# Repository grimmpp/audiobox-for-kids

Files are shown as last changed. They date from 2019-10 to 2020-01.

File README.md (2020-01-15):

# AudioBox for Kids (Arduino and DFMiniPlayer Project)
This project is about an audiobox which allows small kids, who cannot read, don't understand signs, or don't know which button to push, an easy way to choose sound effects, audio books, or music tracks. Playing tracks can be done by putting small items on the top of the audiobox. Those items are related to the e.g. audio book kids want to play and can be e.g. small figures or labelled cards or other NFC tags. 
<br />
<table border=0><tr>
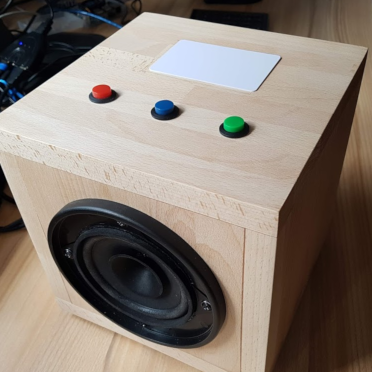
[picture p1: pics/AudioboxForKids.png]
  <td></td>
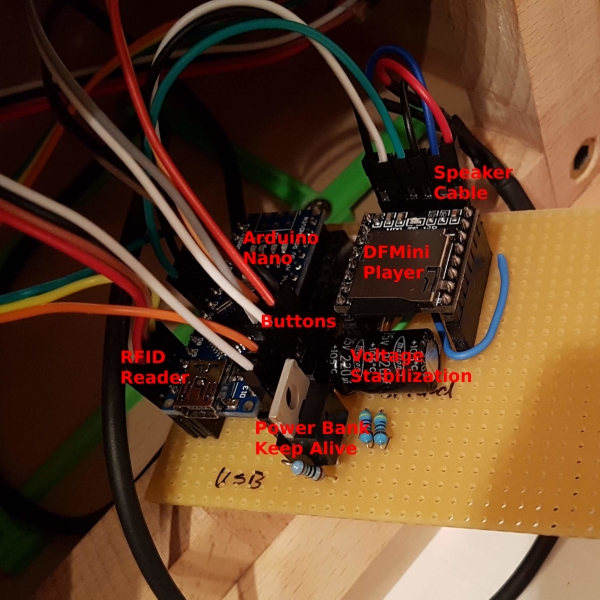
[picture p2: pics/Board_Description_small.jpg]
  <td></td>
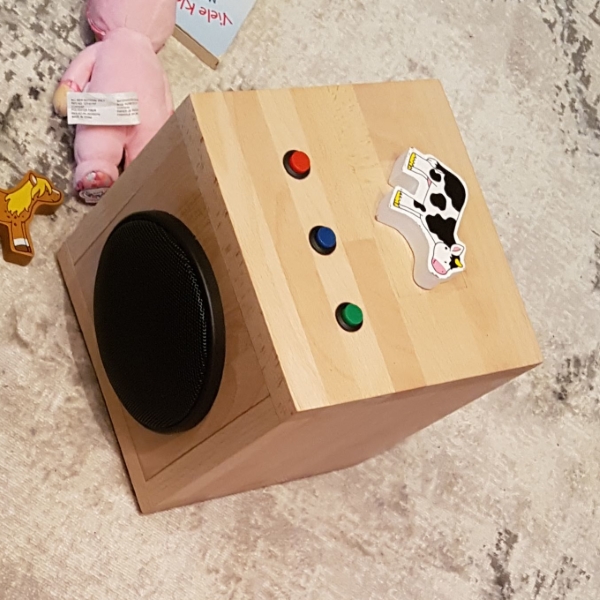
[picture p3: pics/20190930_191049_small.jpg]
  <td></td>
</tr></table>

## Content
* **[What can it do?](#what-can-it-do)**
  * [Play Modes](#play-modes)
  * [Features](#features)
* **[Administration](#administration)**
  * [Copy mp3 files on TF Card (Micro SD Card)](#copy-mp3-files-on-tf-card-micro-sd-card)
  * [Configure NFC Tag](#configure-nfc-tag)
* **[Hardware](#hardware)**
  * [Part List](#part-list)
  * [Schema](#schema)
  * [Case](#case)
  * [NFC Tags](#nfc-tags)
* **[Arduino Software](#arduino-software)**
  * [Why did I choose VS Code and PlatformIO?](#why-did-i-choose-vs-code-and-platformio)
  * [PlatformIO commands](#platformio-commands)
  * [Build with Docker](#build-with-docker)
* **[Sound Tracks](#sound-tracks)**
  * [Animal Sounds](#animal-sounds)
  * [Sound Effects](#sound-effects)
  * [Free Audio Books](#free-audio-books)
  * [Cutting Tool Recommendation](#cutting-tool-recommendation)
  * [Structure of TF Card](#structure-of-tf-card)
  * [How to generate System Sounds for menu?](#how-to-generate-system-sounds-for-menu)
* **[Reconsideration and Outlook](#reconsideration-and-outlook)**
  * [The good things](#the-good-things)
  * [What went not so well](#what-went-not-so-well)
  * [What could be done differently?](#what-could-be-done-differently)
  * [Reconstruction thoughts](#reconstruction-thoughts)
* **[Thanks to Thorsten Voß](#thanks-to-thorsten-voß)**
* **[Links](#links)**

# What can it do?
The audiobox plays a mp3 file which is storage on a TF card (small SD Card) after a RFID/NFC Tag was placed on top of the box. This is the basic function of the audiobox. You can also use the button on top of the audiobox in order to change the volume, switch to the next or previous track, or to pause a audio track.

## Play Modes
* **Audio Book** <br />
After placing a tag on top of the audiobox it starts playing a random track out of the defined folder which is stored on the RFID Tag. After finishing the track the audiobox stops playing other tracks.
* **Album** <br />
Plays all track from the defined folder in the order in which the tracks are stored on the TF Card.
* **Party** <br />
Plays tracks randomly from the defined folder. It does not stop until another RFID Tag is placed or the pause button was pushed.
* **Single Track** <br />
  By placing a NCF Tag on the audiobox it will play only one single track which is configured on the NFC Tag and stops afterwards. <br />
  Button next song and previous song is disabled in this mode.  <br />
  Button play/pause pauses, continuous, or restarts the track after it was finished.
* **Audio Book with Bookmark** <br />
  After placing a tag on top of the box it starts playing an episode. After finishing an episode it stores the number of the next episode on the EEPROM (Arduino's internal persistent memory) so that it can proceed from there next time when the same tag is placed. If not interrupted by the pause button or another tag it will continue playing the next episode. 

## Features
* Plays tracks, albums, songs, audio books, ... by placing NFC Tags on the box.
* Bookmarks for audio books
* Random track selection
* Menu to configure and map the NFC Tags
* Timeout for menus (default 60s)
* Start sound which plays after arduino is initialized
* Button combination to restart Arduino
* Pin-compatible to original [TonUINO](https://www.voss.earth/tonuino/).
* Keep alive logic for power banks (See [PowerBankKeepAliveManager.h](/lib/PowerBankKeepAliveManager/PowerBankKeepAliveManager.h))
* Delay for button for long press mode (See [ButtonManager.h](/lib/ButtonManager/ButtonManager.h))
* Beep which will be played if a button is pushed (planned)

# Administration

## Copy mp3 files on TF Card (Micro SD Card)
Before you can start you need to copy the mp3 files which you want to listen to onto the TF card. Therefore have a look how the structure of the TF Card must look like. In addition to the sound file you want to listen to you need to copy some file for the menus. For deteails have a look [here](/MicroCard-README.md).

## Configure NFC Tag
Before a tag can be used you need to tell the audiobox what should be played. After placing the tag on top of the audiobox the first time the audiobox will ask you and guide you through a menu in order to configure the tag. The following relevant infromation will be stored on the tag: folder number, mode, special field. You need to select a folder in which the mp3 is placed and the Arduino will store the folder number on the tag. After that you need to choose a play mode which is Audio Book, Album, Party, Single Track, Audio Book with Bookmark, or Admin. If you choose Single Track or Admin mode the menu will ask for another track or informaiton that will be stored into the special field. (Bookmarks will be automatically stored direktly on the Arduino's EEPROM so that you can continue listening furhter tracks of an audiobox. Bookmarks don't require space on the tag.)

# Hardware

## [Part List](/part-list.md)

## Schema
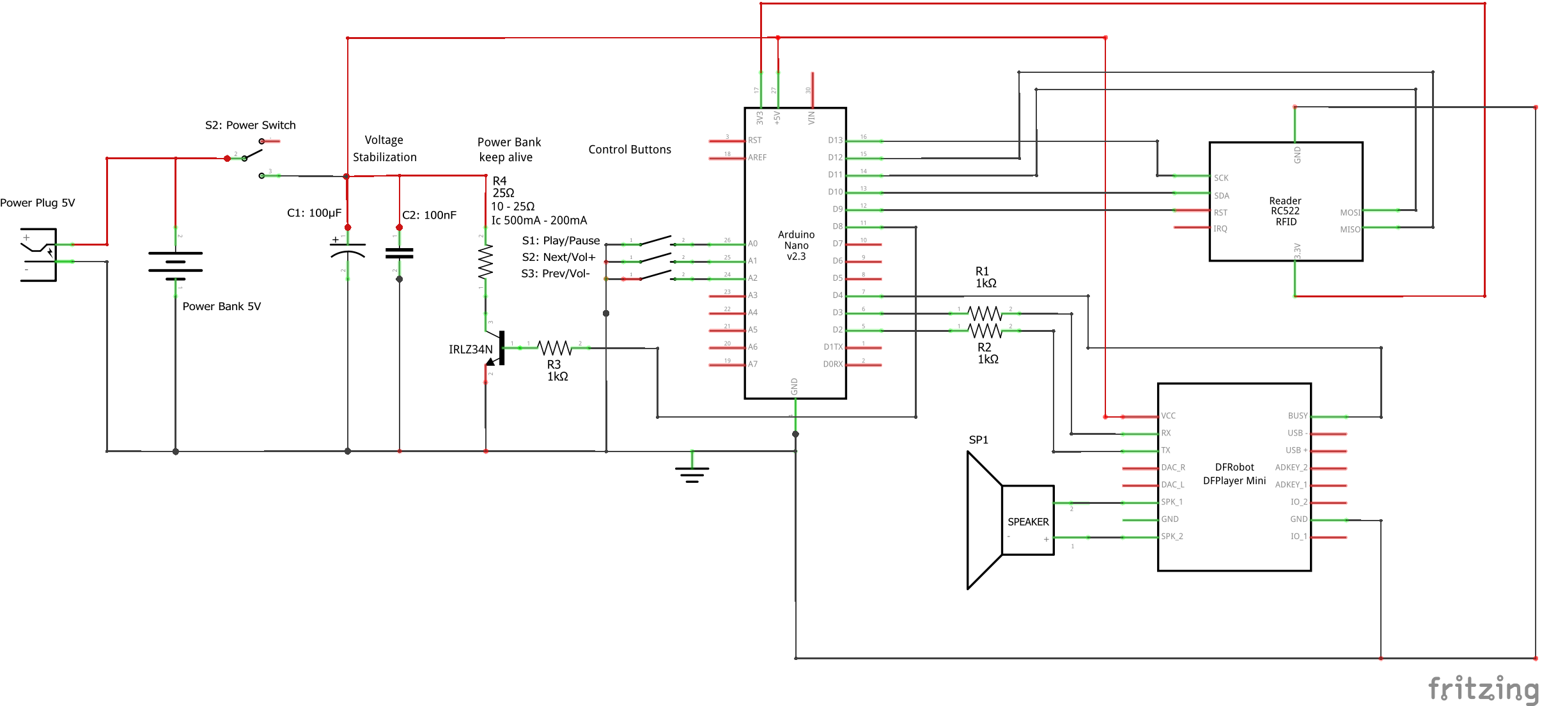
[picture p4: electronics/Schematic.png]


## Case
The case is a simple wooden cube (20cm x 20xm x 20cm). It has three buttons at the top, a speaker at the front, 4 feet at the bottom, and a power jack and a power on/off switch at the back. Inside there is a power bank, the board containing Arduino Nano, DfMiniPlayer, ... and some cable to connect everything.
<table border=0><tr>
  <td></td>
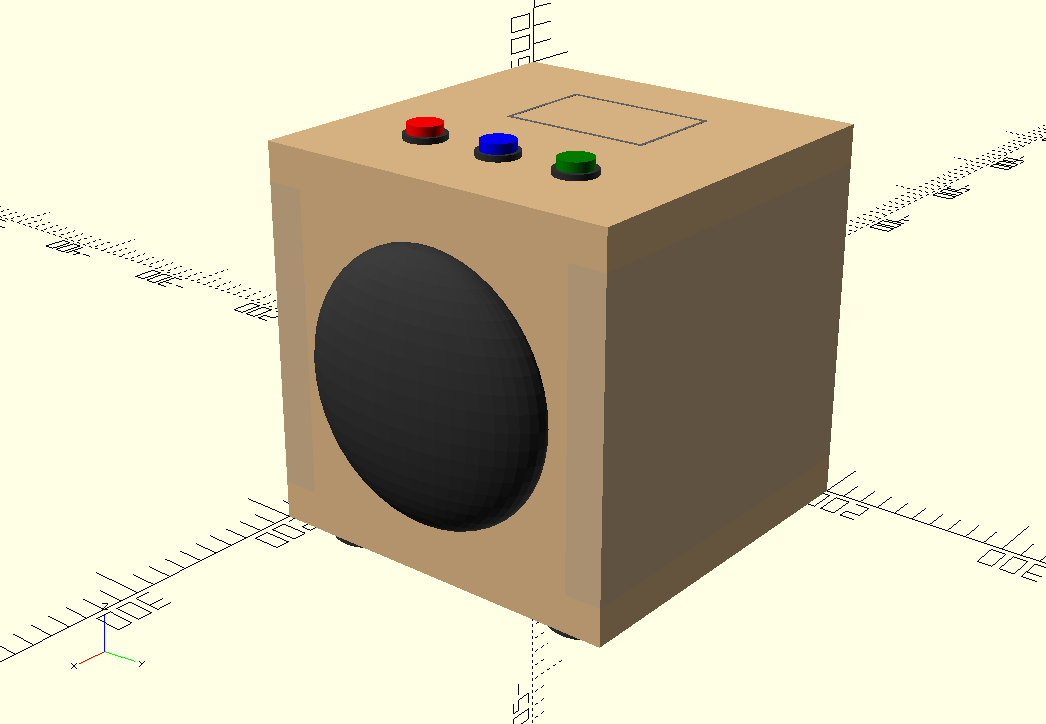
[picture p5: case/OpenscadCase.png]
  <td></td>
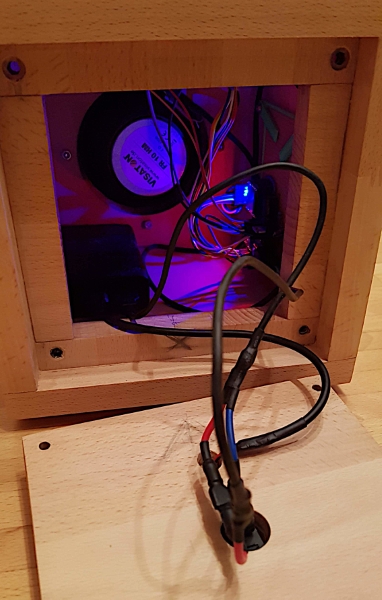
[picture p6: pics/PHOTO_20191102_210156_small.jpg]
  <td></td>
</tr></table>

You can find further pictures from the box in folder [/pics](/pics) and the drawing in folder [/case](/case).

## NFC Tags
In the **[Part List](/part-list.md)** you can find the used NFC Tags. I've created as well small figures from an old wooden puzzle and disassembled NFC Tags which I just fixed with ordenary tape. 
<table border=0><tr>
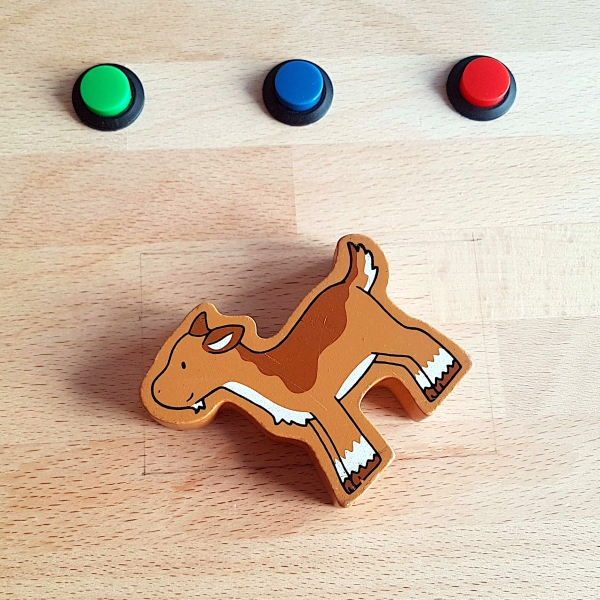
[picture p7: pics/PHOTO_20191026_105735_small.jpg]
  <td></td>
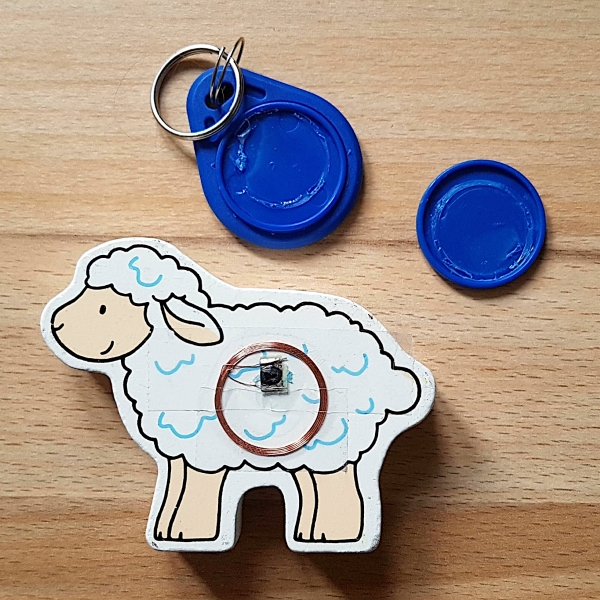
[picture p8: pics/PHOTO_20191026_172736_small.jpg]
  <td></td>
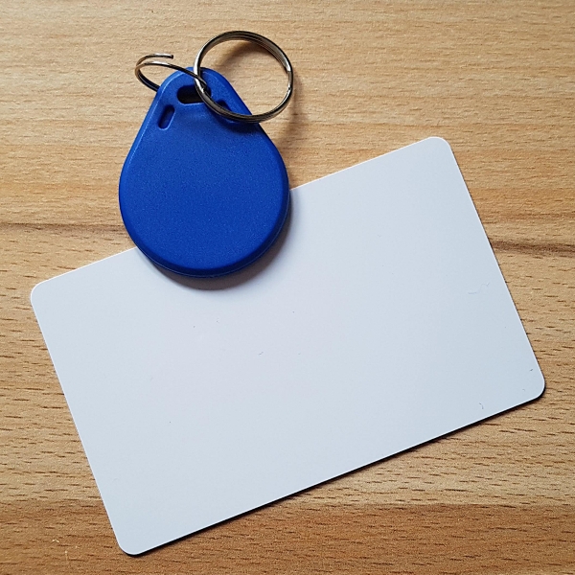
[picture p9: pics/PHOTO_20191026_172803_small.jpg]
  <td></td>
</tr></table>

### How to imprint RFID Cards

For printing the pitures and lables on the RFID Cards I bought self adhesive foil for color laser printers. After printing and cutting them out you can stick them on the RFID Cards.

I found those following nice images, which are free for personal use, on [clipart-library.com](http://clipart-library.com).

<table border=0><tr>
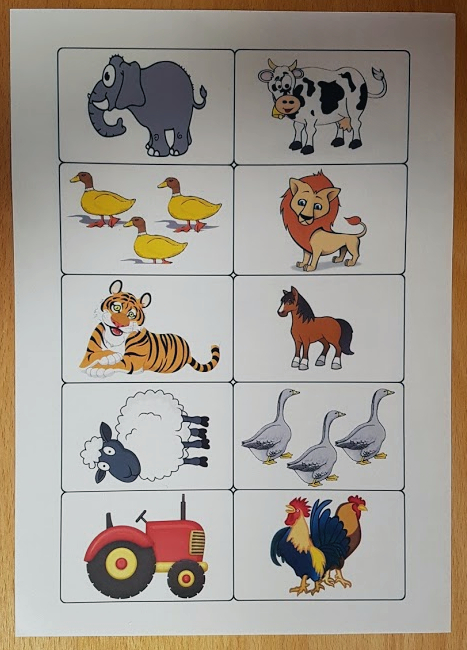
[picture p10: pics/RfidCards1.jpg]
  <td></td>
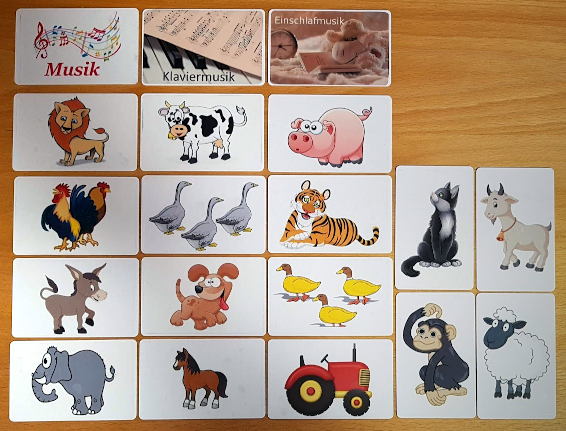
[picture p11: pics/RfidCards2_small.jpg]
  <td></td>
</tr></table>

# Arduino Software
I used [PlatformIO](https://platformio.org/) and [VS Code](https://code.visualstudio.com/) in order to develop the software for this project which runs on an Arduino Nano.
## Why did I choose VS Code and PlatformIO?
* [VS Code](https://code.visualstudio.com/) is a proper IDE
  * Shows instantly compiler information
  * Has autocompletion
  * Shows documentation of libraries and functions
  * Shows e.g. what a library supports by using autocompletion
  * Terminal is attached below code window part
  * ...
* [PlatformIO](https://platformio.org/) 
  * Can really easily resolve C-dependencies (dependent libraries)
  * Can be used independently from IDE in command line.
  * Code verification in docker container possible. 
    * Independent of local environment and easy reproducable
  * Supports a lot of controllers and ICs.
  * Code can be easily split up.
  * Projects can be organized.
  * Upload and monitoring to/of Arduino Nano easily possible.
  * ...

## PlatformIO commands
* Build code: **`pio run`**
* Build and upload code: **`pio run -v -t upload`**
* Open serial monitor: **`pio device monitor -b 115200`**

## Build with Docker
**`docker build -t audiobox /docker/Dockerfile`** <br />
This command builds a docker image based on ubuntu. It contains [platformio](https://platformio.org/), downloads this git repo and builds the code and audio files for the audiobox. Building everything the first time takes quite a while until all dependencies are downloaded and everything is built. Please, be a bit patient. :-)

### Upload binaries onto Arduino with docker
After creating the docker image, which also builds the project automatically, you can start the docker container and upload the binaries onto an Arduino Nano by using the following command: <br />
**`docker run -w /home/audiobox-for-kids --privileged audiobox pio run -v -t upload`** <br />
PlatformIO will automatically search for the usb port in which your Arduino Nano is plugged in. <Br />
*--privileged* is used in this case because we need access to the usb ports. Alternatively you can also enable the usb ports by specifying an argument which maps the host usb ports to container usb ports.

### Docker commands
* Build docker image: **`docker build -t audiobox /docker/Dockerfile`**
* Run docker image: **`docker docker run -it audiobox`**
* Upload to Arduino Nano: **`docker run -w /home/audiobox-for-kids --privileged audiobox pio run -v -t upload`**

Inside the docker image you can e.g. run the platformIO commands.

# Sound Tracks
Beside music and audio books which you own, I was interested in sound effects e.g. for the start sound or when a button gets pushed. Below you can find a list of links where I was able to find the one or other nice sound effect which answered my purpose. 

## Animal Sounds
I've created some little wooden figures with RFID Tag on the back. The corresponding sound files I've used you can find on the following listed page:
* [Free Animal Sounds](https://freeanimalsounds.org/de/download-tierstimmen/)
* [FindSounds](https://www.findsounds.com/ISAPI/search.dll)

## Sound Effects
* [soundjay.com](https://www.soundjay.com/)
* [partnersinrhyme.com](https://www.partnersinrhyme.com/)
* [freesoundeffects.com](https://www.freesoundeffects.com/)
* [soundbible.com](http://soundbible.com/)

## Free Audio Books
* [gratis-hoerspiele.de](https://www.gratis-hoerspiele.de/)

## Cutting Tool Recommendation
Sometimes sound tracks start with a little silence in the beginning, especially if it is a sound effect or animal sound I want the audiobox to respond directly on the ncf tag. That's why I often remove this little silence in the beginning or end of sound tracks. Often it is also needed to adapt the volume of a sound track. I haven't tried out a lot of tools but I'm quite happy with [mp3DirectCut](https://mpesch3.de/) and that's why I recommend it here.

## [Structure of TF Card](MicroCard-README.md)
There is also a nice tool for renaming and copying sound files onto the TF Card. See [TinoTool](/MicroCard-README.md#tinotool) ([Original GitRepo: TinoTool](https://github.com/DarthBrento/TinoTool)). I really like this tool because it reduces a lot of unwanted effort and it is very convenient to have for this case a GUI.

## [How to generate System Sounds for menu?](SystemSounds-README.md)

# Reconsideration and Outlook
In this section I want to highlight what went good and bad and maybe more interesting what would I change next time or could be done in addition.

## The good things
TODO: ...
* **Detection of NFC Cards**
* **Building the electronics**
* **Following Thorstens [guide](https://www.voss.earth/tonuino/)**
## What went not so well
TODO: ...
* **Broken chip on DfMiniPlayer** 
* **Different chips for DfMiniPlayer**
* **White noise because of bad wiring**
## What could be done differently?
* **External USB Port**: Unfortunately I was not able to find a nice USB jack that I could mount at the back of case. That's why I just use a simple 5V power jack to charge the audiobox. I'd really love to have an external USB connection to the Arduino Nano because now I need to remove all the time the back if I want to upload the code again.
* **External Interface for TF Card**: I decided to keep the TF Card internally so that the kids cannot remove it. The downside is if I want to copy new mp3s on the card I need to remove the whole back.
* **Better Speaker** The quality of the speaker and DfMiniPlayer turned out to be quite good, especially in comparison to the price. Knowing that I would have spent more money for a better or bigger speaker to get a even better sound quality. The bass could be a bit stronger.
## Reconstruction thoughts
TODO: ... ESP? ... [GitRepo: ESP8266Audio](https://github.com/earlephilhower/ESP8266Audio)

# Thanks to Thorsten Voß
Thorsten Voß had the brilliant idea to build such a audiobox for little kids. He realized his idea also with almost the same parts. His tutorial and big community is really great and inspired me a lot.
* [Website TonUINO](https://www.voss.earth/tonuino/)
* [Community TonUINO](https://discourse.voss.earth/)
* [GitHub Repository TonUINO](https://github.com/xfjx/TonUINO)

In the community a lot of hard- and software issues are discussed and solved. There is also a [big variety of ideas how to build a case](https://discourse.voss.earth/t/tonuino-gehaeuse-galerie/786). Thorsten also offers a [board](https://discourse.voss.earth/t/neue-platine-version-1-51/63) on which you can put the Arduino Nano, DfMiniPlayer, and to which you can connect the RFID Reader. (Wake up logic for Power Bank is not included.)

# Links
* [PlatformIO](https://platformio.org/) 
* [VS Code](https://code.visualstudio.com/)
* [DFRobot: DfPlayer Mini](https://wiki.dfrobot.com/DFPlayer_Mini_SKU_DFR0299)
* [DF Mini Player - Datasheet](/FN-M16P+Embedded+MP3+Audio+Module+Datasheet.pdf) ([original link](https://github.com/DFRobot/DFRobotDFPlayerMini/blob/master/doc/FN-M16P%2BEmbedded%2BMP3%2BAudio%2BModule%2BDatasheet.pdf))
* [Lib: DFPlayer Mini Mp3 by Makuna](https://github.com/Makuna/DFMiniMp3/blob/master/src/DFMiniMp3.h)
* [Lib: JC_Button](https://github.com/JChristensen/JC_Button)
* [mp3DirectCut](https://mpesch3.de/)
* [Website TonUINO](https://www.voss.earth/tonuino/)
* [Community TonUINO](https://discourse.voss.earth/)
* TonUINO Repos
  * [GitHub Repo original TonUINO from Thorsten Voß](https://github.com/xfjx/TonUINO)
  * [GitHub Repo TonUINO from uluzox](https://github.com/uluzox/TonUINO)

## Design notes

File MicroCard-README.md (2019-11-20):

## Structure of TF Card (Micro SD Card)

Below you can find the structure of the TF Card.

### Storing tracks on TF Card
For storing mp3 and wav tracks you can create folder starting with 01 until 99.
Each folder can contain between 1 and 255 mp3 tracks. The track names must start with numbers. Optionally names can be added after the number.

### [TinoTool](https://github.com/DarthBrento/TinoTool)
There is a nice tooling called [TinoTool](https://github.com/DarthBrento/TinoTool) which can rename your songs and copy them into the corresponding folder into your TF Card.
I made a copy of the binary and placed it into the folder [tooling](/tooling). Unfortunately, it only works under Windows but does its job perfectly. <br />
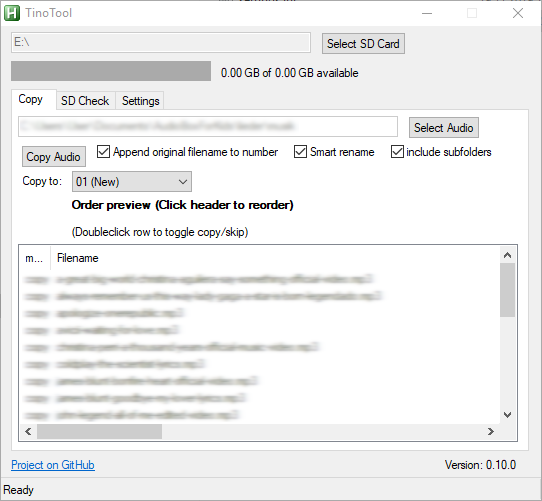
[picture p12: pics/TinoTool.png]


### System Sounds
There are two special folders *mp3* and *advert*. Those two folder contain the file for the system sounds. The system sounds are prepared in this project.

### Known difficulties and recommendations
* Tracks must be stored in the same order like they are named onto the TF Card. Otherwise the mapping will not work.
* I do not recommend to put file into the main folder.
* Use simple filenames
* Do not store other files on the TF Card because this can confuse the DfMiniPlayer
  * Mac users can use this command in order to get rid of unnecessary files: `$ dot_clean /Volumes/SD-Karte`

```
sd:/
   ├── 01
       ├── 001_*.mp3
       ├── ...
       ├── 255_*.mp3
   ├── ...
   ├── 99
       ├── 001_*.mp3
       ├── ...
       ├── 255_*.mp3
   ├── advert
       ├── 0001.mp3
       ├── ...
       ├── 0255.mp3
   ├── mp3
       ├── 0001.mp3
       ├── ...
       ├── 0255.mp3
       ├── 0300_new_tag.mp3 
       ├── 0310_tag_linked.mp3 
       ├── 0311_mode_random_episode.mp3 
       ├── 0312_mode_album.mp3 
       ├── 0313_mode_party.mp3 
       ├── 0314_mode_single_track.mp3 
       ├── 0315_mode_audio_book.mp3 
       ├── 0316_admin.mp3 
       ├── 0320_select_file.mp3 
       ├── 0330_say_number_ask.mp3 
       ├── 0331_say_number_no.mp3 
       ├── 0332_say_number_yes.mp3 
       ├── 0350_buttonSound.mp3
       ├── 0400_tag_ok.mp3 
       ├── 0401_error.mp3 
       ├── 0500_start_sound.mp3
       ├── 0800_reset_tag.mp3 
       ├── 0801_reset_tag_ok.mp3 
       ├── 0802_reset_aborted.mp3 
       ├── 0999_reset_ok.mp3 
```

Details can be found in the [datasheet](/FN-M16P+Embedded+MP3+Audio+Module+Datasheet.pdf) ([original link](https://github.com/DFRobot/DFRobotDFPlayerMini/blob/master/doc/FN-M16P%2BEmbedded%2BMP3%2BAudio%2BModule%2BDatasheet.pdf)) under *3.6.5 Specify playback of a track in a folder*.

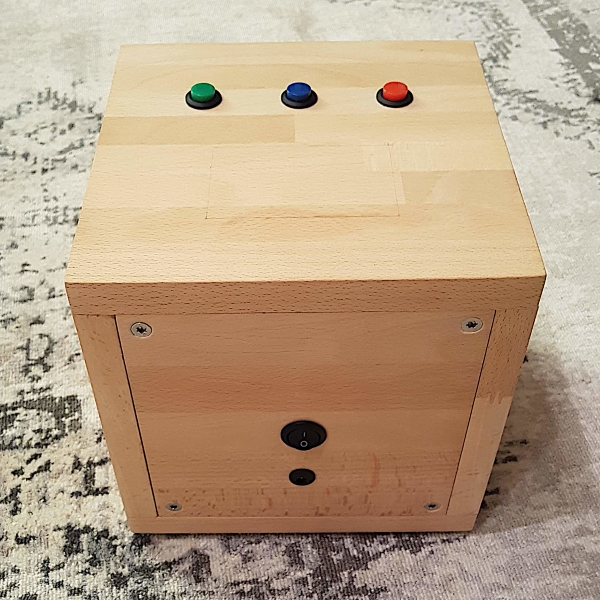
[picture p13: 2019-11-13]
pics/PHOTO_20191102_201601_small.jpg

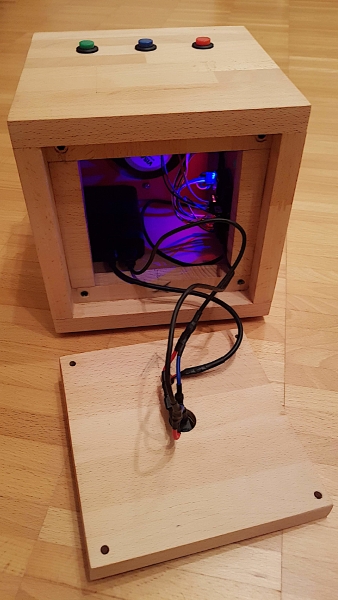
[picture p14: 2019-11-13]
pics/PHOTO_20191102_210108_small.jpg

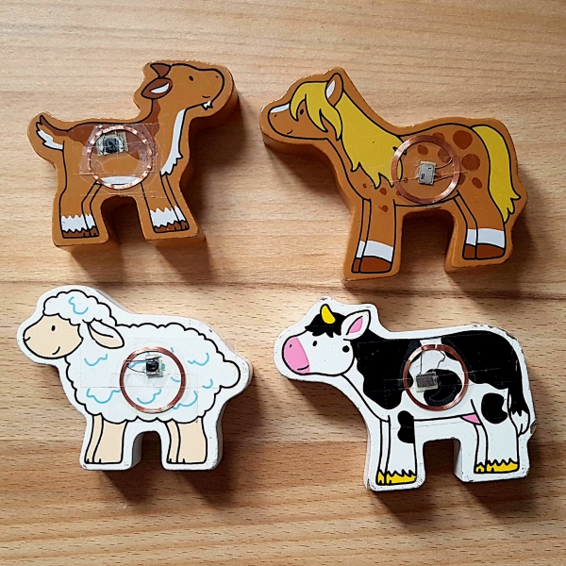
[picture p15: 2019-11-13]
pics/PHOTO_20191026_172718_small.jpg

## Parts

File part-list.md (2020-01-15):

# Parts
* **Arduino Nano** with ATmega328 (old bootloader in this case) (See Starter Kit for TonUINO)
  Depending on wich version you buy you need to configure your project/IDE so that the bootloader is compatible. New versions have a better and faster bootloader. 
* **DFMiniPlayer** [Spec](https://wiki.dfrobot.com/DFPlayer_Mini_SKU_DFR0299#target_1) (See Starter Kit for TonUINO) <br />
  (There are a lot of modules with different controllers/decoders. Ensure you buy one with MH-ET LIVE (MH2024K-24SS) e.g. [this one](https://www.ebay.de/itm/Arduino-WeMos-MP3-Player-Decoder-Modul-Card-Reader-MH2024K-DFPlayer-UART-3-3-5V/283613104099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). This one has a really good sound quality and runs stable. I really had problems with other decoders which made white noice and did not work stable. [Here](http://discourse.voss.earth/t/dfplayer-verschiedene-versionen/681/13) is also a deeper discussion and experiences about the decoders.)
* **RFID Reader RC522** (See Starter Kit for TonUINO)
* Electrolytic **capacitor 100µF** for voltage stabilization
* Film **capacitor 100nF** for voltage stabilization
* **Resistors** 2x1KΩ for UART communication btw Arduino and DfMiniPlayer and 1kΩ + 25Ω (or in my case 2x50Ω in parallel) for power bank keep alive logic
* **Transistor** IRLZ34N (bit oversized) for power bank keep alive logic. Transistor must handle current between 200mA and 500mA.
* **Speaker** ([FR 10 HM - 4 Ohm](https://www.visaton.de/de/produkte/chassiszubehoer/breitband-systeme/fr-10-hm-4-ohm)) [Amazon Offer](https://www.amazon.de/Visaton-schwarz-Lautsprecher-22000-Hz-kabelgebunden/dp/B003A63NLE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)
* **Speaker Net** [Amazon Offer](https://www.amazon.de/tomzz-Audio-2800-000-Lautsprecher-Kunststoffring/dp/B00OM0AXI8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)
* **3 Buttons** (Next/VolUp, Play/Pause, Prev/VolDown) [Amazon Offer](https://www.amazon.de/gp/product/B076SK1HMM/ref=ppx_yo_dt_b_asin_title_o03_s00?ie=UTF8&psc=1)
* **Power Switch**
* **Power Jack**
* **External Power Adapter** (5V Charger)
* **Power Bank** (RAVPower 10000mAh) as battery [Amazon Offer](https://www.amazon.de/gp/product/B075ZNG92W/ref=ppx_yo_dt_b_asin_title_o02_s00?ie=UTF8&psc=1) <br />
  Power Banks have a smart logic which switches the power bank off after about 30sec if the load is too small. Therefore I build a logic to keep it alive.
* **Cable for wiring**
* **Perfboard** <br />
  You can actually also buy the [board](https://discourse.voss.earth/t/neue-platine-version-1-51/63) designed by Thorsten Voß. The board from Thorsten Voß unfortunately does not contain a logic to keep the power bank alive.
* Screws and glue for mounting all parts
* **Case** <br />
  Let you get inspired by this nice [posts](https://discourse.voss.earth/t/tonuino-gehaeuse-galerie/786).
* **TF Card** (max. 32GB) for storing the mp3 files.
* **RFID Keycard MF S50 13,56 MHz** for selecting the tracks. [Amazon Offer](https://www.amazon.de/gp/product/B07TVJPTM7/ref=ppx_yo_dt_b_asin_title_o00_s00?ie=UTF8&psc=1)
* **NFC Tags 13,56 MHz** for selecting the tracks. [Amazon Offer](https://www.amazon.de/gp/product/B077JTT3NQ/ref=ppx_yo_dt_b_asin_title_o01_s00?ie=UTF8&psc=1)
* **NFC Stickers NTAG 215 13,56 MHz** for selecting the tracks [Amazon Offer](https://www.amazon.de/gp/product/B06Y1BLLD4/ref=ppx_yo_dt_b_asin_title_o00_s00?ie=UTF8&psc=1)
* **Self Adhesive foil** for creating stickers in order to label and imprint the RFID Cards [Amazon Offer](https://www.amazon.de/gp/product/B0070WNLB6/ref=ppx_yo_dt_b_search_asin_image)

See also **Starter Kit TonUINO** on [Amazon Offer](https://www.amazon.de/AZDelivery-TonUINO-Arduino-Player-Karten/dp/B07JLBGYQ6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)

# Software
* **Arduino Software** which is contained in this git repo.
* **System Sound Files** which is contained in this git repo.
* **Your mp3 files** you want to play.

# Hardware Tooling
* Ususal stuff like wire cutter, screw driver, ...
* Soldering station
* Depending what kind of case you build: saw, drill, 3D-printer, ...

# Software Tooling
* [Platformio (pio)](https://docs.platformio.org/en/latest/ide/vscode.html) (required for building and pushing code to arduino)
* [VSCode](https://code.visualstudio.com/) (optional only required for chaning code) 
* docker (optional for running platformio in docker container / portable version)

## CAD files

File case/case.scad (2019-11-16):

//This file was created in openscad
//Cheatsheet for openscad http://www.openscad.org/cheatsheet/

w=20;
l=200;

//bottom
color("BurlyWood") cube([l,l,w]);
//top
color("BurlyWood") translate([0,0,l-w]) cube([l,l,w]);
//left
color("Tan") translate([0,0,w]) cube([l,w,l-2*w]);
//right
color("Tan") translate([0,l-w,w]) cube([l,w,l-2*w]);

//back
//color("BurlyWood") translate([0,w,w]) cube([w,l-2*w,l-2*w]);

BackSupport();

//front
color("BurlyWood") translate([l-w,w,w]) cube([w,l-2*w,l-2*w]);

SpeakerFront();
Feet();
Buttons();
CardMark();

module BackSupport() {
    //back support bottom
    color("Wheat") translate([w,w,w]) cube([w,l-2*w,w]);
    //back support top
    color("Wheat") translate([w,w,l-2*w]) cube([w,l-2*w,w]);
    //back support right
    color("Wheat") translate([w,l-2*w,w]) cube([w,w,l-2*w]);
    //back support right
    color("Wheat") translate([w,w,w]) cube([w,w,l-2*w]);
    Nuts();
}

module SpeakerFront() {
    //difference() {
        color([0.2,0.2,0.2]) translate([l,l/2,l/2]) scale([0.4,1,1]) sphere($fn=50, d=140);
        //translate([l-w,w,w]) cube([w,l-2*w,l-2*w]);
    //}
}

module Feet() {
    d=30;
    translate([d,d,-10]) color([0.2,0.2,0.2]) cylinder($fn=36, h=10, d=40);
    translate([d,l-d,-10]) color([0.2,0.2,0.2]) cylinder($fn=36, h=10, d=40);
    translate([l-d,d,-10]) color([0.2,0.2,0.2]) cylinder($fn=36, h=10, d=40);
    translate([l-d,l-d,-10]) color([0.2,0.2,0.2]) cylinder($fn=36, h=10, d=40);
}

module Buttons() {
    translate([l-50,l/2-45,l]) Button("red");
    translate([l-50,l/2,l]) Button("blue");
    translate([l-50,l/2+45,l]) Button("green");
}

module Button(c) {
    color([0.2,0.2,0.2]) cylinder($fn=100, d=22, h=3);
    color(c) cylinder($fn=100, d=18, h=8);
}

module CardMark() {
    color([0.4,0.4,0.4]) translate([l/2-60,l/2-40,l]) cube([54,2,0.1]);
    color([0.4,0.4,0.4]) translate([l/2-60,l/2+40,l]) cube([54,2,0.1]);
    color([0.4,0.4,0.4]) translate([l/2-60+54,l/2+41-81,l]) cube([2,82,0.1]);
    color([0.4,0.4,0.4]) translate([l/2-60,l/2+41-81,l]) cube([2,82,0.1]);
}

module Nuts() {
    translate([w,w+10,w+10]) Nut();    
    translate([w,l-w-10,w+10]) Nut();
    translate([w,l-w-10,l-w-10]) Nut();
    translate([w,w+10,l-w-10]) Nut();
}

module Nut() {
    translate([-0.1,0,0]) color("Goldenrod") rotate([0,90,0]) rotate([0,0,30]) cylinder($fn=6, h=0.1, d=12);
    translate([-0.2,0,0]) color("DimGray") rotate([0,90,0]) cylinder($fn=36, h=0.1, d=5);
}

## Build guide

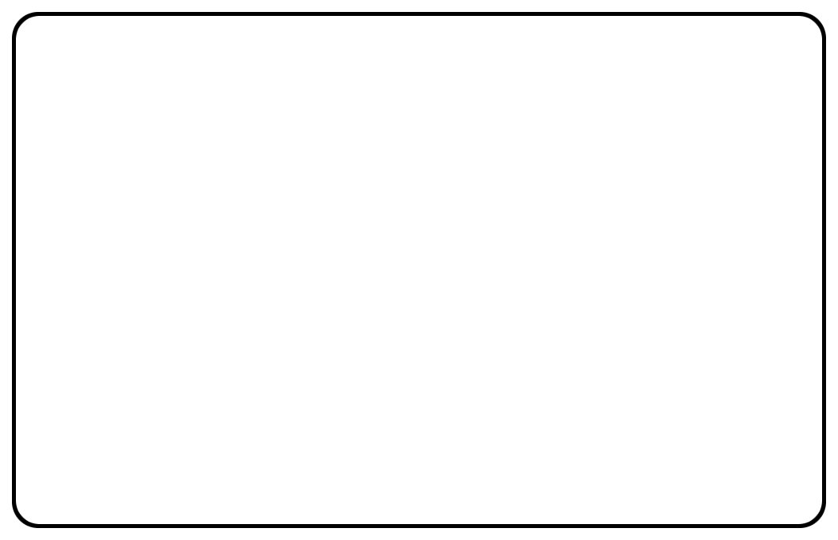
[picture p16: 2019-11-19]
print-template-rfid-card/FrameBlack.png

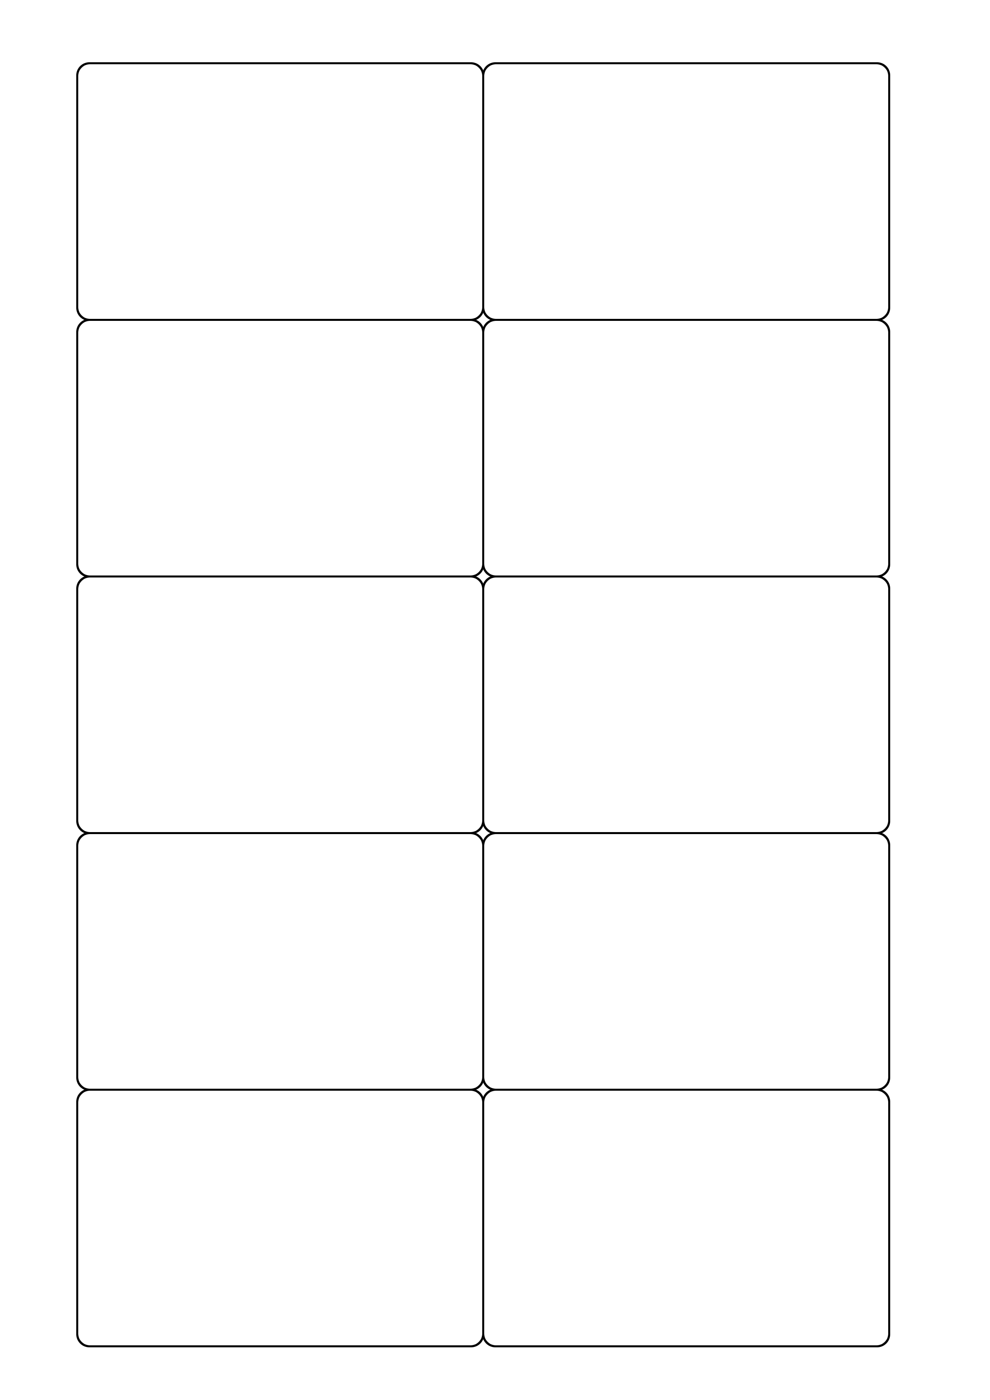
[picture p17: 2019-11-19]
print-template-rfid-card/BlackFramesOnA4.png

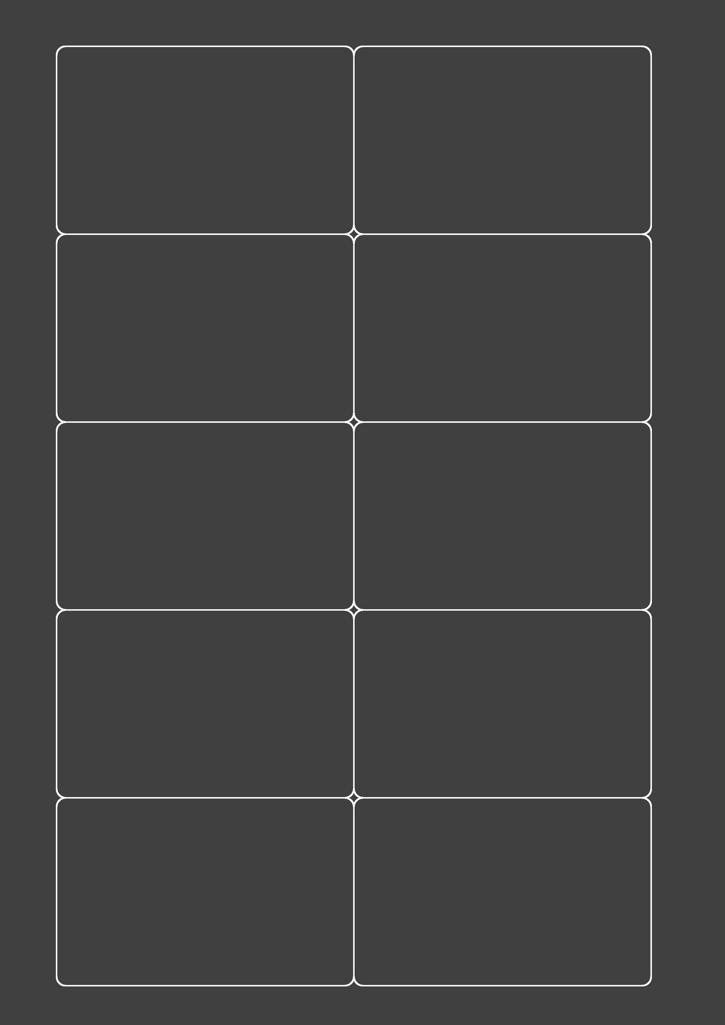
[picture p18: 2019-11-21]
print-template-rfid-card/WhiteFramesOnA4.png

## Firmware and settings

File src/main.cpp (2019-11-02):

#include <Arduino.h>
#include <EEPROM.h>

#include <ArduinoLog.h>
// https://github.com/thijse/Arduino-Log/blob/master/examples/Log/Log.ino

// local references
#include "NfcData.h"
#include "SystemSound.h"
#include "RfidReader.h"
#include "Mp3Player.h"
#include "ButtonManager.h"
#include "Controller.h"
#include "PowerBankKeepAliveManager.h"

// serial interface for log messages
#define SERIAL_BAUD 115200

// Busy Pin for mp3 player
#define BUSY_PIN 4
// Software serial for mp3 player
#define MP3_PLAYER_RX_PIN 2
#define MP3_PLAYER_TX_PIN 3

// Button Pins
#define BUTTON_PLAY_PIN A0
#define BUTTON_UP_PIN A1
#define BUTTON_DOWN_PIN A2

#define LONG_PRESS 500

// RFID Reader
#define RST_PIN 9
#define SS_PIN 10

// Mp3Player
#define INIT_VOLUME 10
#define MAX_VOLUME_LIMIT 20

//Power Bank Keep Alive
#define PB_KEEP_ALIVE_PIN 8
#define PB_KEEP_ALIVE_INTERVAL_MS 4000
#define PB_KEEP_ALIVE_PULS_LENGTH_MS 150

// timeout for menu.
// After timeout the program is going to go back into main loop
#define MENU_TIMEOUT_MS 60000 //60 sec

uint8_t voiceMenu(uint16_t numberOfOptions, SystemSound::ID startMessage, uint8_t messageOffset,
              bool preview = false, uint8_t previewFromFolder = 0);
bool resetCard(void);
NfcTag setupCard(NfcTag oldCard);
void resetEEPROMOption(void);
bool checkMenuTimeout(void);

NfcTag nfcCard;
Controller *controller;
Mp3Player * mp3Player;
RfidReader *rfidReader;
ButtonManager *buttonManager;
PowerBankKeepAliveManager *pbkaMgr;
unsigned long menuTimeStart = 0;


void setup() {

  Serial.begin(SERIAL_BAUD); 

  Log.begin(LOG_LEVEL_VERBOSE, &Serial);

  Log.notice(F(CR "**********************************" CR));
  Log.notice(F("Software - Philipp Grimm" CR));
  Log.notice(F("**********************************" CR CR));

  Log.trace(F("Start initializing hardware." CR));

  // Init random generator
  Log.trace(F("Init random generator." CR));
  randomSeed(analogRead(A0));

  // Button with PullUp
  Log.trace(F("Init pullup buttons." CR));
  buttonManager = new ButtonManager(LONG_PRESS, BUTTON_DOWN_PIN, BUTTON_PLAY_PIN, BUTTON_UP_PIN);

  // NFC Reader
  Log.trace(F("Init NFC reader: "));
  rfidReader = new RfidReader(SS_PIN, RST_PIN);
  rfidReader->init(true);

  resetEEPROMOption();

  Log.notice(F("Init PowerBankKeepAliveManager" CR));
  pbkaMgr = new PowerBankKeepAliveManager(PB_KEEP_ALIVE_PIN, PB_KEEP_ALIVE_INTERVAL_MS, PB_KEEP_ALIVE_PULS_LENGTH_MS);
  
  Log.notice(F("Init Controller" CR));
  controller = new Controller();

  // DFPlayer Mini initialisieren
  Log.notice(F("Init mp3 player." CR));
  mp3Player = new Mp3Player(MP3_PLAYER_RX_PIN, MP3_PLAYER_TX_PIN, BUSY_PIN, controller);
  Log.notice(F("Disable function sleep for mp3Player." CR));
  mp3Player->enableSleep(false);
  mp3Player->setVolume(INIT_VOLUME);
  mp3Player->setMaxVolumeLimit(MAX_VOLUME_LIMIT);

  controller->setMp3Player(mp3Player);
  
  delay(500);
  Log.notice(F("Start welcome sound." CR));
  mp3Player->playSystemSounds(SystemSound::START_SOUND);
  mp3Player->waitUntilTrackIsFinished();

  Log.trace(F("Initialization completed." CR CR));
}


void loop() {
  Log.notice(F("In loop." CR));
  do {
    pbkaMgr->loop();
    mp3Player->loop();
    buttonManager->readAllButtons();

    buttonManager->restartOption();

    if (buttonManager->isPlayButtonPressedForLong()) {
      Log.notice(F("Play button pressed for longer than 1 sec." CR));
      buttonManager->waitForPlayButtonToBeReleased();

      if (mp3Player->isPlaying()) {
        Log.notice(F("Advertise current track." CR));
        mp3Player->playAdvertisement(mp3Player->getCurrentTrack());
      } else {
        // mp3Player->playAdvertisement(SystemSound::BUTTON_SOUND);
        if (resetCard()) {
          nfcCard = setupCard(nfcCard);
          controller->playTrack(nfcCard);
        }
        rfidReader->halt();
      }
    }
    else if (buttonManager->wasPlayButtonReleased()) {
      if (mp3Player->isPlaying()) {
        Log.notice(F("Pause current track." CR));
        mp3Player->pause();
        // mp3Player->playAdvertisement(SystemSound::BUTTON_SOUND);
      }
      else {
        Log.notice(F("Continue current track." CR));
        // mp3Player->playAdvertisement(SystemSound::BUTTON_SOUND);
        mp3Player->start();
      }
    }

    if (buttonManager->isUpButtonPressedForLong()) {
      Log.notice(F("Volume Up" CR));
      mp3Player->increaseVolume();
      // mp3Player->playAdvertisement(SystemSound::BUTTON_SOUND);
    } else if (buttonManager->wasUpButtonReleased()) {
      Log.notice(F("Next button was pressed." CR));
      // mp3Player->playAdvertisement(SystemSound::BUTTON_SOUND);
      controller->nextTrack(random(65536));
    }

    if (buttonManager->isDownButtonPressedForLong()) {
      Log.notice(F("Volume Down" CR));
      mp3Player->decreaseVolume();
      // mp3Player->playAdvertisement(SystemSound::BUTTON_SOUND);
    } else if (buttonManager->wasDownButtonReleased()) {
      Log.notice(F("Previous button was pressed." CR));
      // mp3Player->playAdvertisement(SystemSound::BUTTON_SOUND);
      // mp3Player->playAdvertisement(1);
      controller->previousTrack();
    }
    
    buttonManager->resetButtonDelayForLongPress();

  } while (!rfidReader->isNewCardPresent());

  // RFID card was placed
  Log.notice(F("New card has been detected. " CR));

  if (!rfidReader->readCardSerial()) {
    Log.notice(F("Cannot read card!" CR));
    rfidReader->reset();
    return;
  }

  if (rfidReader->readCard(&nfcCard)) {
      
    if (nfcCard.cookie == 322417479 && nfcCard.folder != 0 && nfcCard.mode != 0) {
        controller->playTrack(nfcCard);
    }
    else {
      // Configure new nfc card
      nfcCard = setupCard(nfcCard);
      controller->playTrack(nfcCard);
    }

    rfidReader->halt();
  } else {
    rfidReader->reset();
  }
}

/**
 * Press all buttons for 1sec at start time to delete complete EEPROM
 */
void resetEEPROMOption() {
  if (digitalRead(BUTTON_PLAY_PIN) == LOW && digitalRead(BUTTON_UP_PIN) == LOW && digitalRead(BUTTON_DOWN_PIN) == LOW) {
    Log.notice(F("Reset -> clean EEPROM"));
    for (uint16_t i = 0; i < EEPROM.length(); i++) {
      EEPROM.write(i, 0);
    }
  }
}

bool checkMenuTimeout() {
  if (millis() - menuTimeStart > MENU_TIMEOUT_MS) {
    Log.notice(F("Exit menu because of timeout: %dms" CR), MENU_TIMEOUT_MS);
    return true;
  }
  return false;
}

void playPreview(SystemSound::ID messageOffset, bool preview, uint8_t previewFromFolder, uint8_t returnValue){
  mp3Player->playSystemSounds((SystemSound::ID) (messageOffset + returnValue));
  pbkaMgr->loop();
  delay(1000);
  if (preview) {
    do {
      delay(10);
    } while (mp3Player->isPlaying());

    if (previewFromFolder == 0) mp3Player->playFolderTrack(returnValue, 1);
    else mp3Player->playFolderTrack(previewFromFolder, returnValue);
  }
}

uint8_t voiceMenu(uint16_t numberOfOptions, SystemSound::ID startMessage, SystemSound::ID messageOffset,
              bool preview = false, uint8_t previewFromFolder = 0) {
  uint8_t returnValue = 0;
  if (startMessage != SystemSound::UNKNOWN) mp3Player->playSystemSounds(startMessage);

  menuTimeStart = millis();
  do {
    pbkaMgr->loop();
    mp3Player->loop();
    buttonManager->readAllButtons();
    buttonManager->restartOption();
    if (checkMenuTimeout()) return 0;

    if (buttonManager->isUpButtonPressedForLong()) {
      Log.notice(F("UpButton pressed for long." CR));
      returnValue = min(returnValue + 10, numberOfOptions);
      playPreview(messageOffset, preview, previewFromFolder, returnValue);

    } else if (buttonManager->wasUpButtonReleased()) {
      Log.notice(F("UpButton was released." CR));
      returnValue = min(returnValue + 1, numberOfOptions);
      playPreview(messageOffset, preview, previewFromFolder, returnValue);
    }
    
    if (buttonManager->isDownButtonPressedForLong()) {
      Log.notice(F("DownButton pressed for long." CR));
      returnValue = max(returnValue - 10, 1);
      playPreview(messageOffset, preview, previewFromFolder, returnValue);

    } else if (buttonManager->wasDownButtonReleased()) {
      Log.notice(F("DownButton was released." CR));
      returnValue = max(returnValue - 1, 1);
      playPreview(messageOffset, preview, previewFromFolder, returnValue);
    }

    buttonManager->resetButtonDelayForLongPress();

  } while ( !(returnValue != 0 && buttonManager->wasPlayButtonReleased()) );

  return returnValue;
}

bool resetCard() {
  Log.notice(F("Reset Nfc Card: " CR));
  mp3Player->playSystemSounds(SystemSound::RESET_TAG);

  menuTimeStart = millis();
  do {
    pbkaMgr->loop();
    buttonManager->readAllButtons();
    buttonManager->restartOption();
    if (checkMenuTimeout()) return false;

    if (buttonManager->wasUpButtonReleased() || buttonManager->wasDownButtonReleased()) {
      Log.notice(F("Reset Card was cancelled." CR));
      mp3Player->playSystemSounds(SystemSound::RESET_ABORTED);
      return false;
    }
  } while (!rfidReader->isNewCardPresent());

  if (!rfidReader->readCardSerial()) {
    mp3Player->playSystemSounds(SystemSound::ERROR);
    return false;
  }
  Log.notice(F("NFC Card was recognized!" CR));

  Log.notice(F("Reset card and write to card empty data." CR));
  NfcTag nfcCard;
  nfcCard.cookie = 0;
  nfcCard.folder = 0;
  nfcCard.mode = 0;
  nfcCard.special = 0;
  nfcCard.version = 0;

  if (rfidReader->writeCard(nfcCard)) {
    Log.notice(F("Nfc card was successfully reset." CR));
    return true;
  } 
  else {
    mp3Player->playSystemSounds(SystemSound::ERROR);
    return false;
  }
}

NfcTag setupCard(NfcTag oldCard) {
  NfcTag ncfCard = oldCard;
  mp3Player->pause();
  Log.notice(F("Configure new card:" CR));

  // Ask for mapping folder
  Log.notice(F("Start menu to define folder." CR));
  ncfCard.folder = voiceMenu(99, SystemSound::NEW_TAG, (SystemSound::ID)0, true);
  if (ncfCard.folder == 0) return oldCard;

  // Ask for play mode
  Log.notice(F("Start menu to define play mode." CR));
  ncfCard.mode = voiceMenu(6, SystemSound::TAG_LINKED, SystemSound::TAG_LINKED);
  if (ncfCard.mode == 0) return oldCard;

  // Create bookmark 
  Log.notice(F("Create bookmark for new folder" CR));
  EEPROM.write(ncfCard.folder,1);

  // Ask for single track in case of single track mode
  if (ncfCard.mode == NFC_CARD_MODE::SINGLE_TRACK) {
    Log.notice(F("Start menu to define single track." CR));
    ncfCard.special = voiceMenu(mp3Player->getFolderTrackCount(ncfCard.folder), 
                                SystemSound::SELECT_FILE, (SystemSound::ID)0,
                                true, ncfCard.folder);
  }

  // Admin Mode
  if (ncfCard.mode == NFC_CARD_MODE::ADMIN) {
    Log.notice(F("Start menu to define file for admin mode." CR));
    ncfCard.special = voiceMenu(3, SystemSound::SELECT_FILE, SystemSound::SELECT_FILE);
  }

  // Configuration completed ... write data to card
  mp3Player->pause();
  if (rfidReader->writeCard(ncfCard)) {
    Log.notice(F("Wrote data to nfc tag successfully."));
    return ncfCard;
  } 
  else {
    mp3Player->playSystemSounds(SystemSound::ERROR);
    return oldCard;
  }

}

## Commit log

2019-10-11 continuous improvement
    [Schematic.fzz]
2019-10-21 ButtonManager created
2019-10-22 Schematic updated
    [Schematic.fzz]
2019-10-22 Changed schematic
    [Schematic.fzz]
2019-10-22 Introduced Power Bank keep alive
2019-10-22 Power Bank Keep Alive added to main
2019-10-23 Adapted Power Bank logic
    [Schematic.fzz]
2019-10-23 adapted schematic
    [Schematic.fzz]
2019-10-24 adapted power bank parameters
2019-10-26 start track after configuring nfc card
2019-11-02 problem with long pressed buttons solved.
2019-11-02 added reset of rfid reader
    [main.cpp]
2019-11-09 added docs for uploading bin to arduino form docker container
2019-11-16 case drawing added
    [case.scad]
2019-11-19 big fix + print templates added
2019-11-21 print template for rfid cards added
